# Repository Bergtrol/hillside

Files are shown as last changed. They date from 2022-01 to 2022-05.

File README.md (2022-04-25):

# Hillside Ergonomic Keyboards

Hillside is a small family of split ergonomic keyboards.

Hillside keyboard with nice!nano and switches Hillside 56, 52 and 48 keyboards

The boards are the:

- [Hillside 56](hillside56) with a physical arrow T cluster fully separate from the alpha keys. The most novice friendly, but the largest.
- [Hillside 52](hillside52) with ring and pinky splay and whose physical arrow keys steal one of the alpha keys. The best all around choice.
- [Hillside 48](hillside48) which is like a Ferris Sweep on steroids. The original and most compact.

Their key differences are:

| Board | Layout  | Arrow <br> T | Finger <br> Splay | Encoder <br> Spots / Side | Hotswap <br> Option| Thin <br> Layout | Thin <br> Size |
|:---|:---|:---:|:---:|:---:|:---:|:---:|:---:|
| [Hillside 56](hillside56) | 3x6+5+5 | yes |  no | 4 | yes | 3x5+4+5 | 48 |
| [Hillside 52](hillside52) | 3x6+3+5 | yes |  yes | 3 | yes | 3x5+2+5 | 44 |
| [Hillside 48](hillside48) | 3x6+1+5 | no |  no | 1 | no | 3x5+1+5 | 42 |

Their common features are:

- Choc-spaced keys, aggressive stagger, five thumb keys
- Break-off pinky column
- Tenting puck support
- QMK and ZMK firmware
- Nice!nano battery power switch
- Encoder support for one per side
- Haptic feedback header and mount
- Underglow from five SK6812-MINI-Es
- Reversible PCB which qualifies for AllPCB's free PCB
- Detailed BOM and default keyboard rational
- SMT diodes, resistors, capacitors, and reset switch

See the board readmes for details and default keymaps.

*Keycaps*: Hillside boards are _only_ suitable for choc v1 switches and keycaps based on an 18 x 17mm switch spacing, such as the [MBK](https://mkultra.click/mbk-choc-keycaps), [Lowprokb LDSA](https://lowprokb.ca/products/ldsa-low-profile-blank-keycaps) and [MoErgo MCC](https://mkultra.click/moergo-mcc-pom-1u-keycap/). Not MX ones, nor 18 x 18mm ones such as Work Louder, nor Kailh Choc Transparent.

## Hardware

See the [wiki](https://github.com/mmccoyd/hillside/wiki)
  for how to order PCBs and build the boards.

See [Forking and Modifying](https://github.com/mmccoyd/hillside/wiki/Forking%20and%20Modifying)
  on whether it would be difficult to modify these designs.

## Firmware

QMK includes firmware for [Hillside48](https://github.com/qmk/qmk_firmware/tree/master/keyboards/handwired/hillside).

ZMK firmware is at [Hillside ZMK Firmware](https://github.com/mmccoyd/zmk-config).

The default keymap is shared by both and is described in QMK.

## Acknowledgments

The awesome discord communities for Low Profile Keyboards and splitkb.com provided a fertile learning ground.
Several of the symbol and footprint files came from that community, as noted in the doc folder.
The keyboards I have used and read about also influenced these boards, including the
  [Atreus](https://shop.keyboard.io/products/keyboardio-atreus),
  [Lily58](https://github.com/kata0510/Lily58),
  [Kyria](https://splitkb.com/collections/keyboard-kits/products/kyria-pcb-kit),
  [Corne](https://github.com/foostan/crkbd) and
  [Ferris](https://github.com/pierrechevalier83/ferris).

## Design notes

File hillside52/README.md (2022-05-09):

# Hillside 52

Hillside 52 is a split ergonomic keyboard with 3x6+3+5 choc-spaced keys.
It has the aggressive stagger of the Ferris plus
  finger splay, a physical arrow T, a longer thumb arc
  and break-off outer pinky columns.

Hillside52 keyboard Hillside 52 keyboard

The arrow clusters provide a more familiar keymap for users new to small keyboards and provide utility keys for more seasoned users. See the Hillside [family readme](../README.md) for features common to all hillside boards. Specific to the Hillside 52 are: 

* One Encoder per side at either: upper or tucked thumb or lowest ring
* Reversible 100 x 143mm PCB, which qualifies for AllPCB's free PCB offer

## Keymap

The default keymap has physical arrow keys, alternate hand modifiers for all keys and a navigation and editing layer. See the [keymap descrition](https://github.com/mmccoyd/hillside/wiki/Hillside%2052%20Keymap) for details.

Hillside52 keyboard Hillside 52 keyboard three main layers (https://github.com/mmccoyd/hillside/wiki/Hillside%2052%20Keymap)

## Firmware

QMK: a fork I need to push, which will become a PR

<!---

[Hillside58 fork](https://github.com/mmccoyd/qmk_firmware)
to be pushed and added as PR to QMK.
-->

ZMK: TBD

# Why

A visually easy to use keyboard is useful. Either for people new to small keyboards or for a keyboard pulled from a dusty drawer a year from now. The physical arrow cluster of a 65% keyboard makes it more intuitive than a 60% keyboard, so adding an arrow T to a 40% board seemed a way to make using a 40% board more obvious.

I find a few extra keys laying around lets me have multiple approaches to things. This allows me to choose between approaches gradually over time.
Also, the extra keys fit within the existing Hillside48 footprint and the inner arrow might be a good thumb key.

## Images

<div style="background-color:#DCDCDC;">

Schematic
</div>

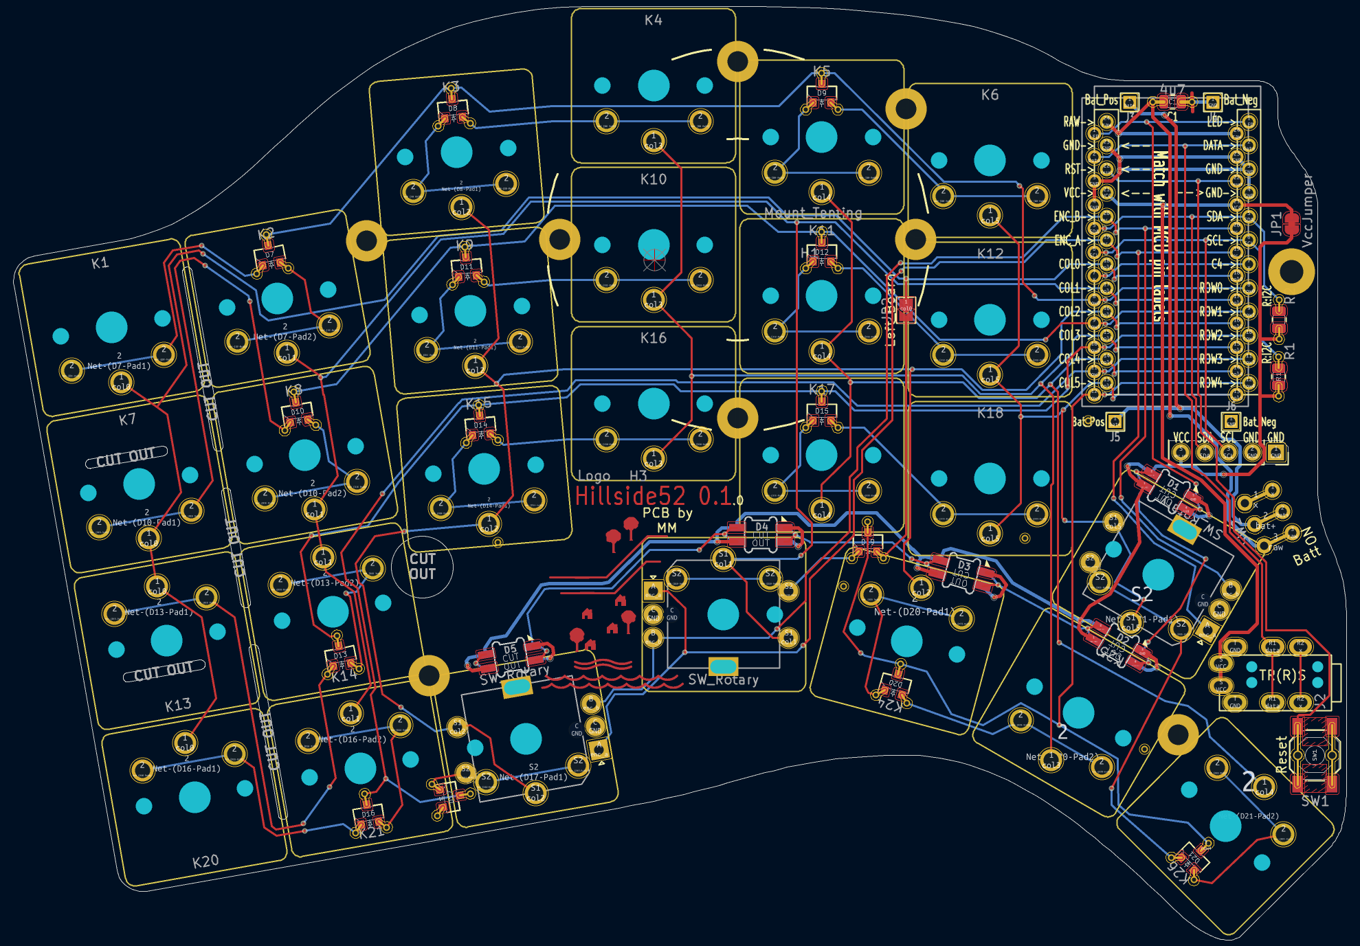
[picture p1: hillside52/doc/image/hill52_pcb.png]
pcb PCB


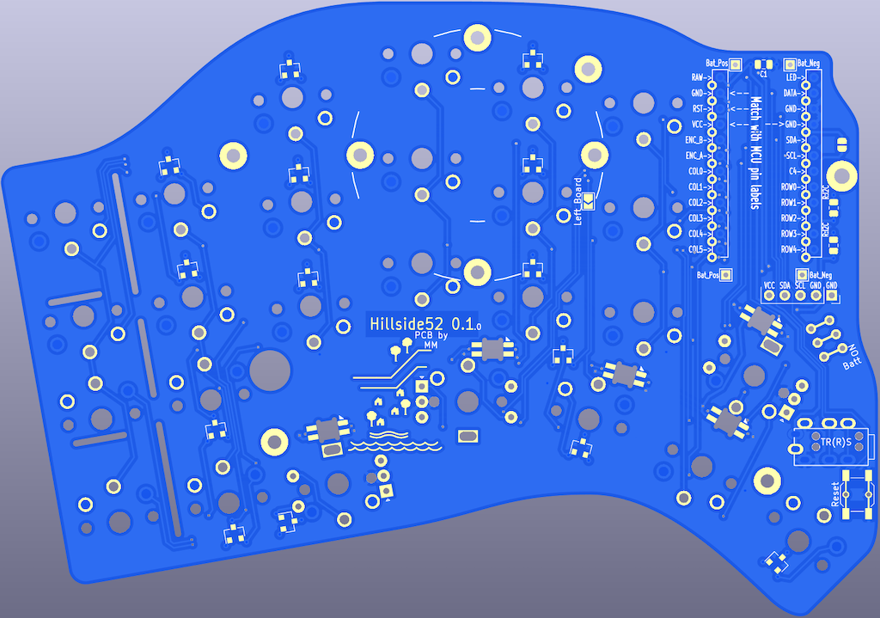
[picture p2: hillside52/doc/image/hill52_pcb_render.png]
render Front Render


<div style="background-color:#DCDCDC;">

To test if the key layout suits your fingers,
 print the below switch layout images in landscape mode.
(The images do not show well on a dark nighttime background.)

switches Switch Layout Left

switches Switch Layout Right
</div>

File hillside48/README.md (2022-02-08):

# Hillside48 Ergonomic Keyboard

Hillside48 is a split ergonomic keyboard with 3x6+4+2 choc-spaced keys. It has the aggressive stagger of the Ferris but a longer thumb arc and a break-off outer pinky column.

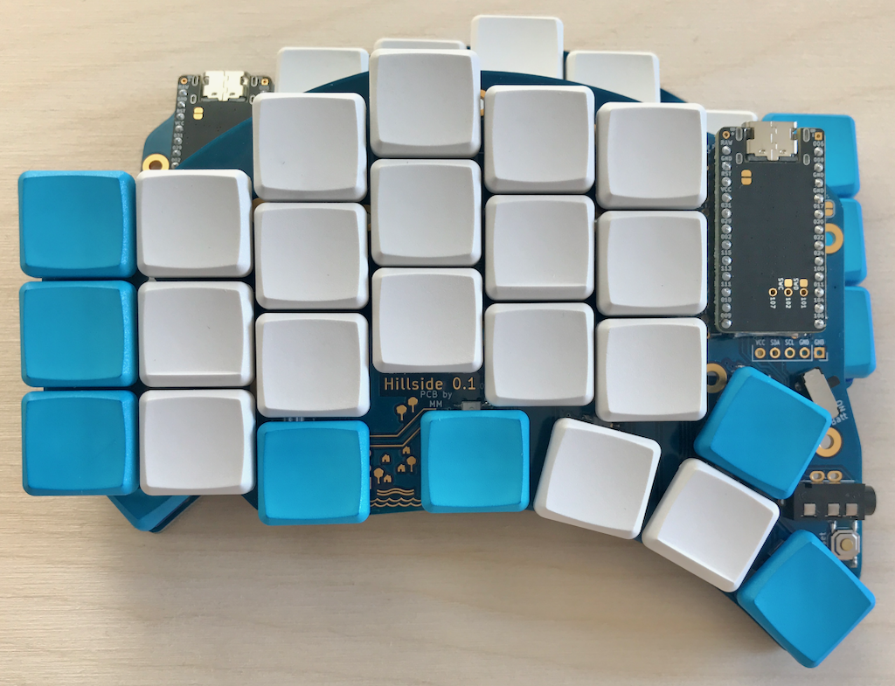
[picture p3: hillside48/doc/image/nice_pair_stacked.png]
Hillside keyboard with nice!nano and switches Keyboard with nice!nano and switches


So rather like a choc Kyria, minus two keys. With 42 to 48 keys it isn't minimalist,
  but it is compact on finger travel while still allowing roomy keymaps.

Features:
- 3x6+4+2 choc-spaced keys, aggressive stagger, four key thumb arc, break-off pinky column
- Tenting puck mount point
- QMK and ZMK firmware
- Nice!nano battery power switch and decoupling capacitor
- Encoder support under the ring fingers
- Haptic feedback header
- Underglow from five SK6812-MINI-Es
- Reversible 99 x 137mm PCB, which qualifies for AllPCB's free PCB offer
- Detailed BOM and default keyboard rational.
- SMT diodes, resistors, capacitors, and reset switch

Hillside48 is _only_ suitable for choc v1 switches and keycaps based on an 18 x 17mm switch spacing, such as the MBK keycaps. Not MX ones, nor 18 x 18mm ones such as Work Louder.

As the first Hillside board, it was originally just Hillside and is also just hillside/0_1 within the QMK firmware.

## Hardware

See the [wiki](https://github.com/mmccoyd/hillside/wiki)
  for how to order the PCB and build the board.
KiCad 6 was used to create the board gerbers.

See [Forking and Modifying](https://github.com/mmccoyd/hillside/wiki/Forking%20and%20Modifying)
  on whether it would be difficult to modify this design, for those that are interested.

## Firmware

QMK includes firmware for [Hillside](https://github.com/qmk/qmk_firmware/tree/master/keyboards/handwired/hillside).

For ZMK, firmware access is at [Hillside ZMK Firmware](https://github.com/mmccoyd/zmk-config).

The default keymap is shared by both and is described in QMK.

# Why

I wanted choc spacing but a key or so more than the Ferris and an outer pinky column. Instead of tweaking the 3x6 choc Corne I started a new PCB for more flexibility, though it grew to fill its footprint....

Moving around the switches of the Choc Corne did seem the easiest approach. But learning more than blind KiCad modification seemed a better idea, so I created a new PCB matching the Ferris column and thumb spacing.

I liked the bottom row keys of my Atreus, so I added two under the middle columns, where they seem unobtrusive. Then one shifted to the thumb arch, which seems more versatile. An upper thumb key seemed useful and combo-able without pushing the footprint. It has more keys than my initial idea, but that makes keymap evolution feel less tight.

It is like a Ferris Sweep on steroids, which wound up close to a Choc Kyria but requires board fabrication and SMT soldering.
Naming ideas included FeistyCorne, LongFir and LongSweep, but Hillside seemed the most fun.

## Acknowledgments

The awesome Low Profile Keyboards and splitkb.com discord communities provided a fertile learning ground for my keyboard explorations.
Several of the symbol and footprint files came from that community, as noted in the doc folder.
The keyboards I have used and read about also influenced this board including the
  [Atreus](https://shop.keyboard.io/products/keyboardio-atreus),
  [Lily58](https://github.com/kata0510/Lily58),
  [Kyria](https://splitkb.com/collections/keyboard-kits/products/kyria-pcb-kit),
  [Corne](https://github.com/foostan/crkbd) and
  [Ferris](https://github.com/pierrechevalier83/ferris).

## Images
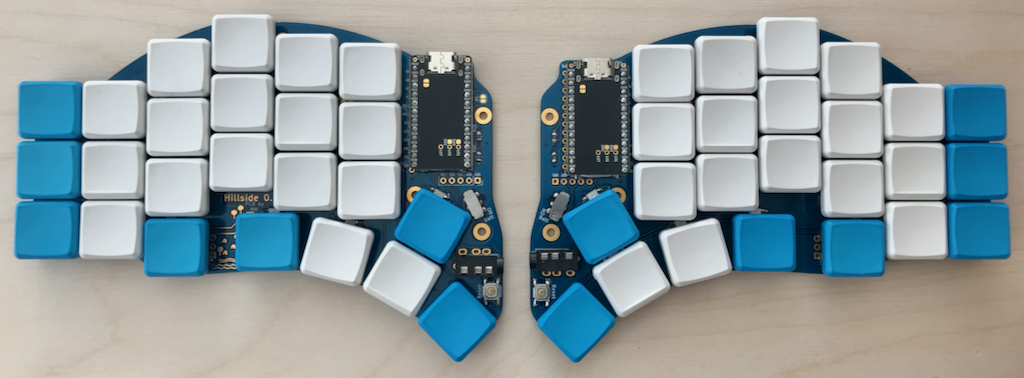
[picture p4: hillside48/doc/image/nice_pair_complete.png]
Both halves


<div style="background-color:#DCDCDC;">

Schematic
</div>

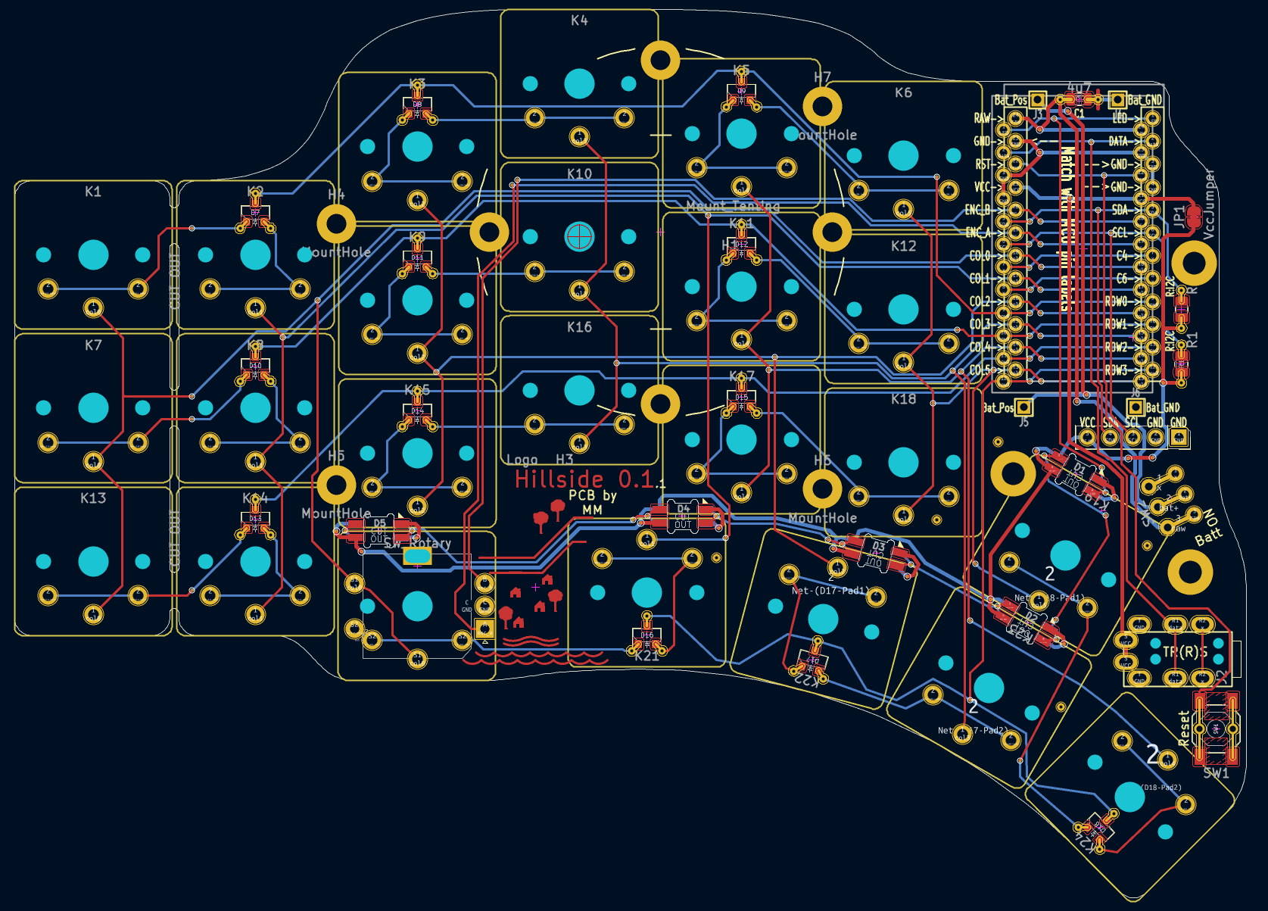
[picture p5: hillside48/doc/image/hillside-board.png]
pcb PCB


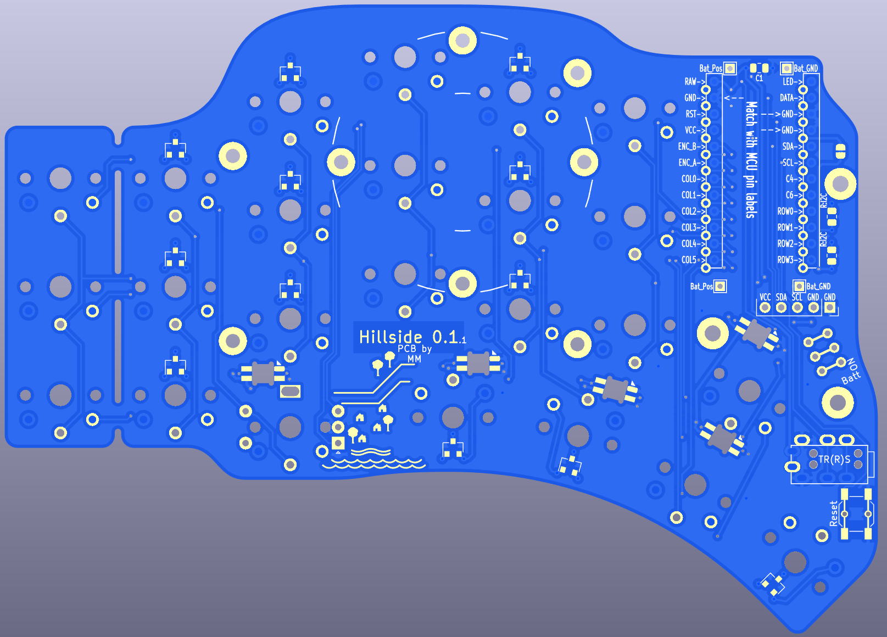
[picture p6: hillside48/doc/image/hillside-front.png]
render Front Render


<div style="background-color:#DCDCDC;">

To test if the key layout suits your fingers,
 print these in landscape mode.
switches Switch Layout Left

switches Switch Layout Right
</div>

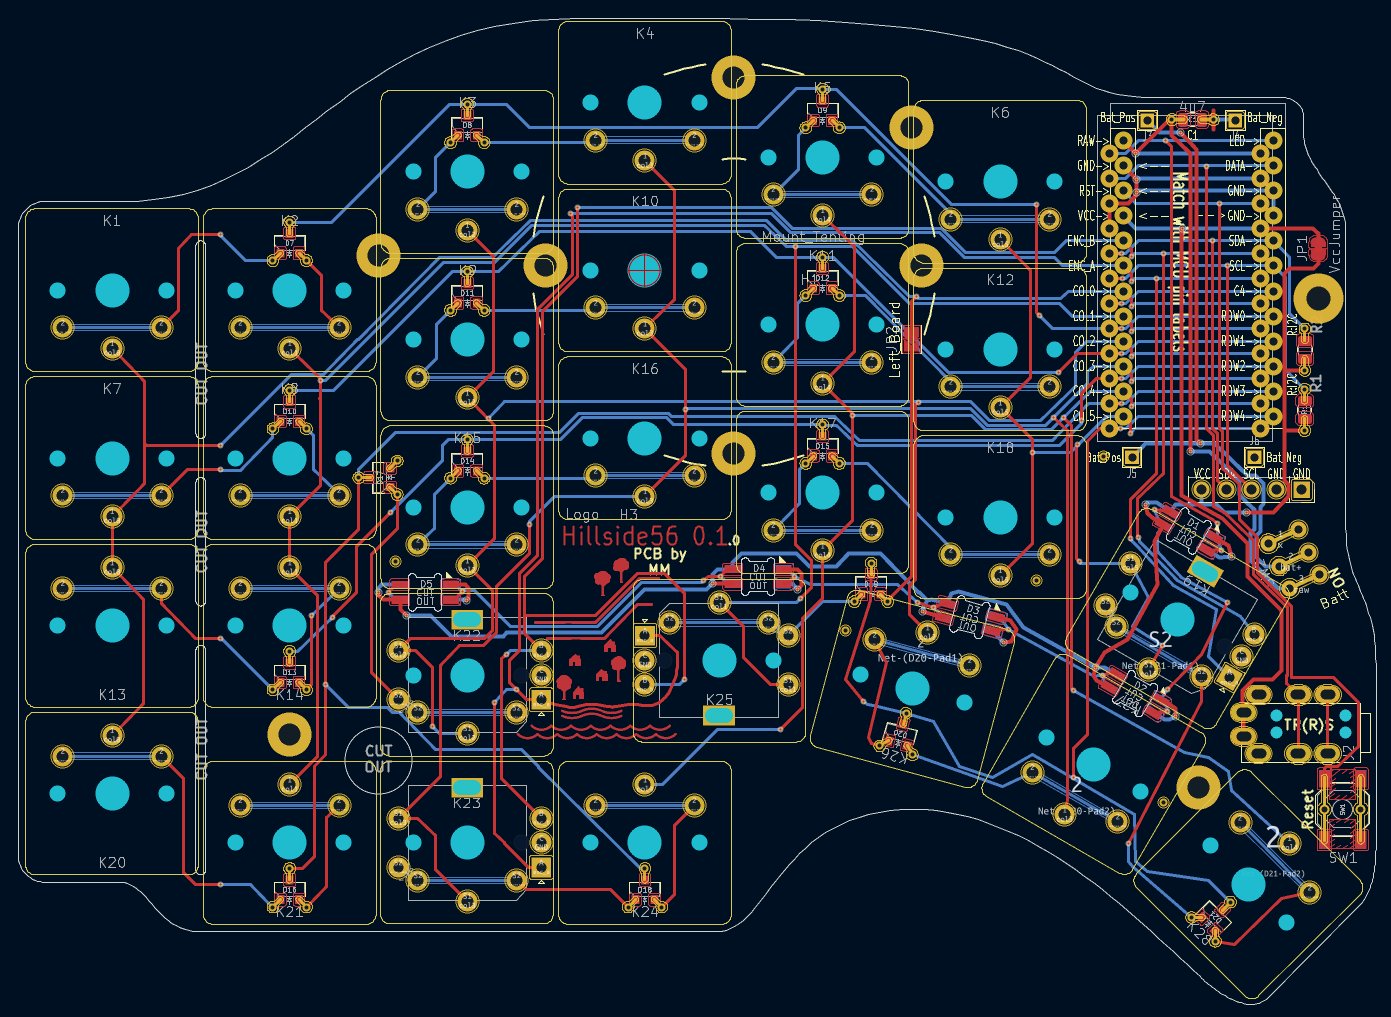
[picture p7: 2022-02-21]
hillside56/doc/image/hill56_pcb.png

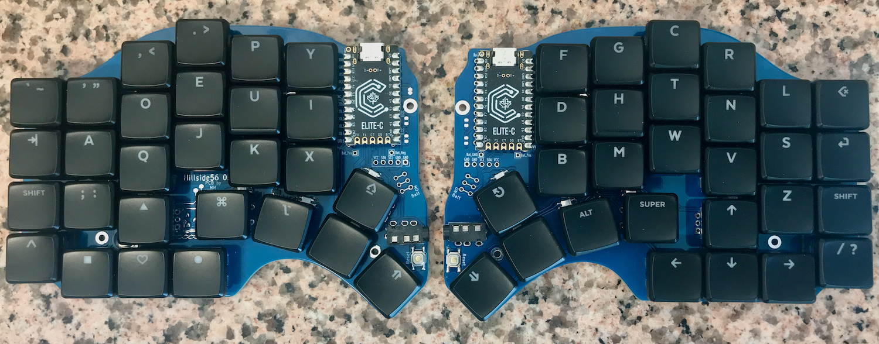
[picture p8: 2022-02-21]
hillside56/doc/image/hill56_photo_pair.png

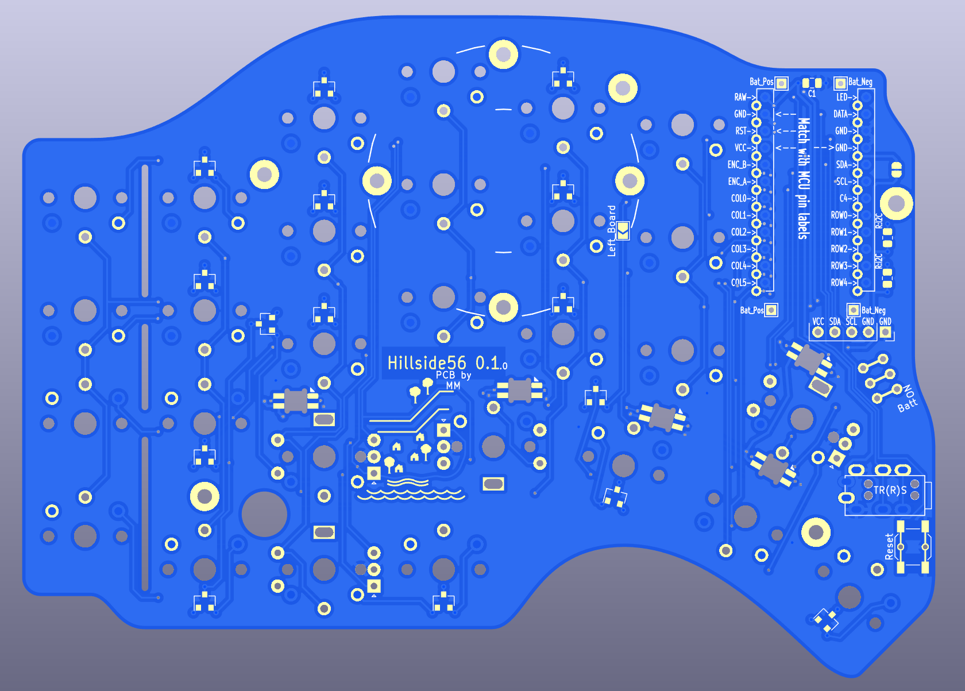
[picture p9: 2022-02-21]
hillside56/doc/image/hill56_pcb_render.png

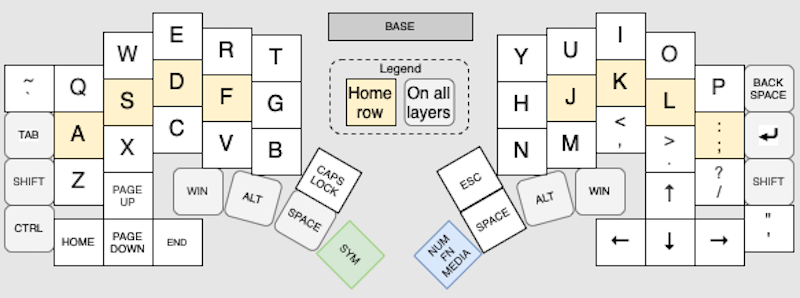
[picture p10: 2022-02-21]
hillside56/doc/image/hill56_keymap.png

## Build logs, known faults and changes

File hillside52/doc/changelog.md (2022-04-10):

# Version 0.1.0

The initial Hillside 52 release. The key differences from the Hillside 48 are:

- Total of 52 keys, adding an extra key under each pinky column.
- Space for physical arrow keys, using one alpha key for the up arrow.
- Splay of five and ten degrees for the ring and pinkey columns.
- Hotswap switch option using Mill-Max sockets.
- Three spots for one encoder per side.
- Cleaner method to remove outer pinky column.

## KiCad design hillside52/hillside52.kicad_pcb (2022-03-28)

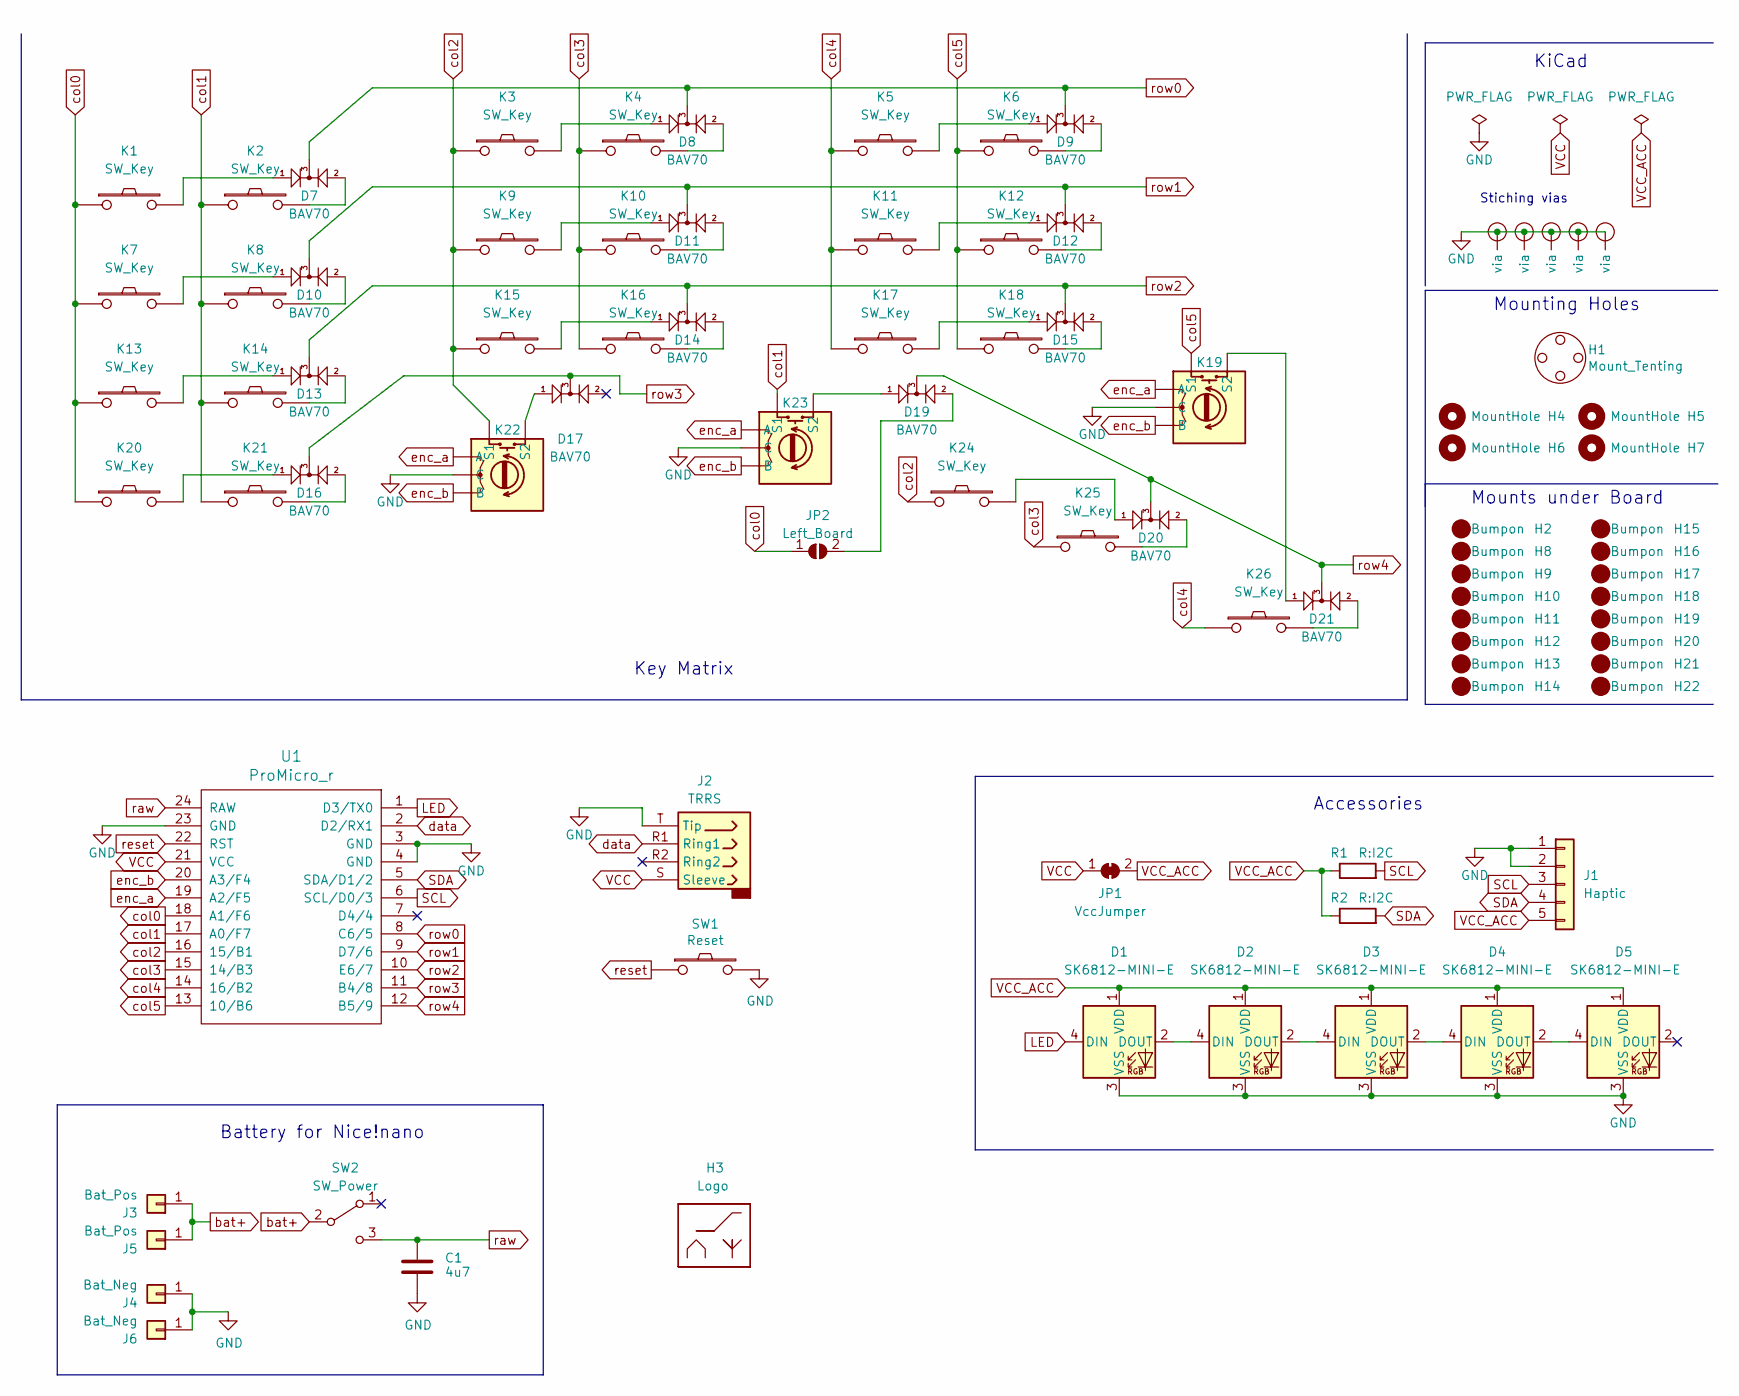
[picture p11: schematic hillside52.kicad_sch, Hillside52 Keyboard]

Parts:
C1: 4u7; C_0805_2012Metric
D1, D2, D3, D4, D5: SK6812-MINI-E
D7, D8, D9, D10, D11, D12, D13, D14, D15, D16, D17, D19, D20, D21: BAV70; SOT-23
H1: Mount_Tenting; Tenting_Puck
H2, H8, H9, H10, H11, H12, H13, H14, H15, H16, H17, H18, H19, H20, H21, H22: Bumpon
H3: Logo; Hillside_Logo
H4, H5, H6, H7: MountHole; MountingHole_2.2mm_with_PCB_insert_rings
J1: Haptic; Pimoroni_Haptic
J2: TRRS; MJ-4PP-9
J3, J5: Bat_Pos; 1pin_conn
J4, J6: Bat_Neg; 1pin_conn
JP1: VccJumper; SolderJumper-2_P1.3mm_Bridged_RoundedPad1.0x1.5mm
JP2: Left_Board; SolderJumper-2_P1.3mm_Open_TrianglePad1.0x1.5mm
K1, K2, K3, K4, K5, K6, K7, K8, K9, K10, K11, K12, K13, K14, K15, K16, K17, K18, K20, K21, K24, K25, K26: SW_Key; pg1350-R_hotswap
K19, K22, K23: SW_Rotary; pg1350-DR_rotary_hotswap
R1, R2: R:I2C; R_0805_2012Metric
SW1: Reset; SW_SPST_SKQG_WithStem
SW2: SW_Power; SW_SPDT_JS202011AQN
U1: ProMicro_r; ProMicro_v2
V1, V2, V3, V4, V5: Via; VIA-0.8mm

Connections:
GND: C1.2, D1.3 (VSS), D2.3 (VSS), D3.3 (VSS), D4.3 (VSS), D5.3 (VSS), J1.1, J1.2, J2.T (Tip), J4.1, J6.1, K19.C, K22.C, K23.C, SW1.2, U1.3 (GND), U1.4 (GND), U1.23 (GND), V1.1 (via), V2.1 (via), V3.1 (via), V4.1 (via), V5.1 (via)
LED: D1.4 (DIN), U1.1 (D3/TX0)
unnamed: D1.2 (DOUT), D2.4 (DIN)
unnamed: D2.2 (DOUT), D3.4 (DIN)
unnamed: D3.2 (DOUT), D4.4 (DIN)
unnamed: D4.2 (DOUT), D5.4 (DIN)
unnamed: D7.1 (A1), K1.2
unnamed: D7.2 (A2), K2.2
unnamed: D8.1 (A1), K3.2
unnamed: D8.2 (A2), K4.2
unnamed: D9.1 (A1), K5.2
unnamed: D9.2 (A2), K6.2
unnamed: D10.1 (A1), K7.2
unnamed: D10.2 (A2), K8.2
unnamed: D11.1 (A1), K9.2
unnamed: D11.2 (A2), K10.2
unnamed: D12.1 (A1), K11.2
unnamed: D12.2 (A2), K12.2
unnamed: D13.1 (A1), K13.2
unnamed: D13.2 (A2), K14.2
unnamed: D14.1 (A1), K15.2
unnamed: D14.2 (A2), K16.2
unnamed: D15.1 (A1), K17.2
unnamed: D15.2 (A2), K18.2
unnamed: D16.1 (A1), K20.2
unnamed: D16.2 (A2), K21.2
unnamed: D17.1 (A1), K22.S2
unnamed: D19.1 (A1), K23.S2
unnamed: D19.2 (A2), JP2.2 (B)
unnamed: D20.1 (A1), K24.2
unnamed: D20.2 (A2), K25.2
unnamed: D21.1 (A1), K19.S2
unnamed: D21.2 (A2), K26.2
SCL: J1.3, R1.2, U1.6 (SCL/D0/3)
SDA: J1.4, R2.2, U1.5 (SDA/D1/2)
VCC: J2.S (Sleeve), JP1.1 (A), U1.21 (VCC)
VCC_ACC: D1.1 (VDD), D2.1 (VDD), D3.1 (VDD), D4.1 (VDD), D5.1 (VDD), J1.5, JP1.2 (B), R1.1, R2.1
bat+: J3.1, J5.1, SW2.2 (B)
col0: JP2.1 (A), K1.1, K7.1, K13.1, K20.1, U1.18 (A1/F6)
col1: K2.1, K8.1, K14.1, K21.1, K23.S1, U1.17 (A0/F7)
col2: K3.1, K9.1, K15.1, K22.S1, K24.1, U1.16 (15/B1)
col3: K4.1, K10.1, K16.1, K25.1, U1.15 (14/B3)
col4: K5.1, K11.1, K17.1, K26.1, U1.14 (16/B2)
col5: K6.1, K12.1, K18.1, K19.S1, U1.13 (10/B6)
data: J2.R1 (Ring1), U1.2 (D2/RX1)
enc_a: K19.A, K22.A, K23.A, U1.19 (A2/F5)
enc_b: K19.B, K22.B, K23.B, U1.20 (A3/F4)
raw: C1.1, SW2.3 (C), U1.24 (RAW)
reset: SW1.1, U1.22 (RST)
row0: D7.3 (K), D8.3 (K), D9.3 (K), U1.8 (C6/5)
row1: D10.3 (K), D11.3 (K), D12.3 (K), U1.9 (D7/6)
row2: D13.3 (K), D14.3 (K), D15.3 (K), U1.10 (E6/7)
row3: D16.3 (K), D17.3 (K), U1.11 (B4/8)
row4: D19.3 (K), D20.3 (K), D21.3 (K), U1.12 (B5/9)

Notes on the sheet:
KiCad
Mounting Holes
Key Matrix
Battery for Nice!nano
Stiching vias
Mounts under Board
Accessories

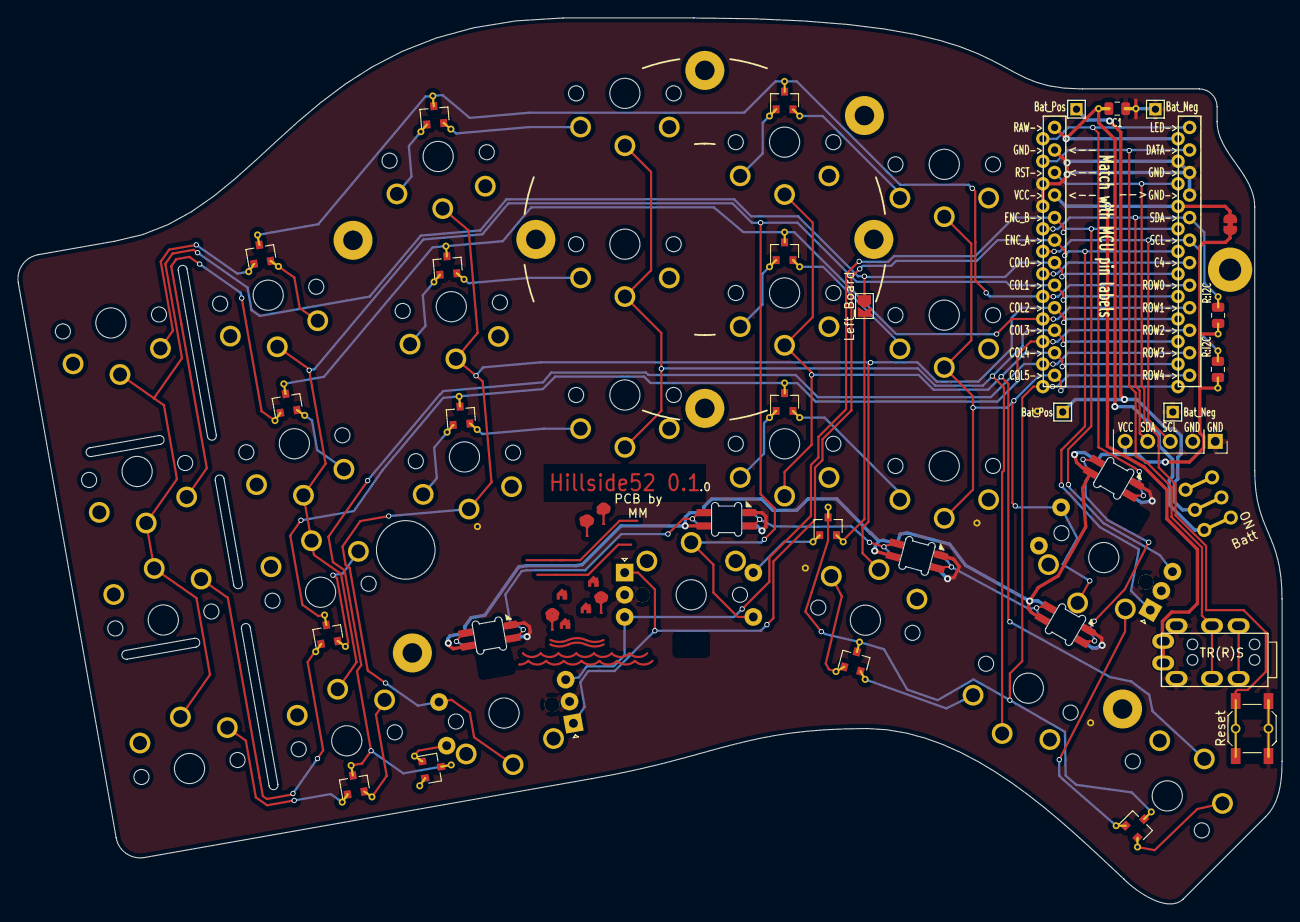
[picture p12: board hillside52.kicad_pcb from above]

Board: 2 copper layers, 142.5 x 99.9 mm, 86 parts (0 on the bottom side), 54 nets.

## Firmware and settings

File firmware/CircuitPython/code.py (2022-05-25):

print("Starting setup...")

import board
from kmk.kmk_keyboard import KMKKeyboard
from kmk.keys import KC
from kmk.modules.layers import Layers

from kmk.scanners.keypad import MatrixScanner

print("Initializing keyboard...")

keyboard = KMKKeyboard()

keyboard.modules.append(Layers())

# keyboard.debug_enabled = True

keyboard.matrix = [
                    MatrixScanner(column_pins=(board.GP5,board.GP4,board.GP3,board.GP2,board.GP1,board.GP0),
                                  row_pins=(board.GP6,board.GP7,board.GP8,board.GP9)),
                    MatrixScanner(column_pins=(board.GP10,board.GP11,board.GP12,board.GP13,board.GP14,board.GP15),
                                  row_pins=(board.GP16,board.GP17,board.GP18,board.GP19))
                  ]

keyboard.coord_mapping = [ 
    0,  1,  2,  3,  4,  5,                  24, 25, 26, 27, 28, 29,
    6,  7,  8,  9,  10, 11,                 30, 31, 32, 33, 34, 35,
    12, 13, 14, 15, 16, 17,                 36, 37, 38, 39, 40, 41,
                           21,           44,
            20,    22, 23, 19, 18,   47, 46, 42, 43,    45,
    ]

# KMK Layer Mods
# --------------
# KC.DF(layer)	    Switches the default layer until the next time the keyboard powers off
# KC.MO(layer)	    Momentarily activates layer, switches off when you let go
# KC.LM(layer, mod)	As MO(layer) but with mod active
# KC.LT(layer, kc)	Momentarily activates layer if held, sends kc if tapped
# KC.TG(layer)	    Toggles the layer (enables it if no active, and vise versa)
# KC.TO(layer)	    Activates layer and deactivates all other layers
# KC.TT(layer)	    Momentarily activates layer if held, toggles it if tapped repeatedly

Num = KC.MO(1)
Nav = KC.MO(2)
Sym = KC.MO(3) 

WordL = KC.LALT(KC.LEFT)
WordR = KC.LALT(KC.RIGHT)

Undo = KC.LGUI(KC.Z)
Cut = KC.LGUI(KC.X)
Copy = KC.LGUI(KC.C)
Paste = KC.LGUI(KC.V)
Redo = KC.LGUI(KC.Y)

vsNavB = KC.LCTL(KC.MINS)
vsNavF = KC.LCTL(KC.LSFT(KC.MINS))
    
keyboard.keymap = [
    # Base layer
    #-------+-------+-------+-------+-------+-------+                                      +-------+-------+-------+-------+-------+-------+
    #  TAB  |   Q   |   W   |   F   |   P   |   G   |                                      |   J   |   L   |   U   |   Y   |   ;   |   '   |
    #-------+-------+-------+-------+-------+-------|                                      |-------+-------+-------+-------+-------+-------|
    #  CRTL |   A   |   R   |   S   |   T   |   D   |                                      |   H   |   N   |   E   |   I   |   O   | ENTER |
    #-------+-------+-------+-------+-------+-------+-------+                      +-------+-------+-------+-------+-------+-------+-------|
    # SHIFT |   Z   |   X   |   C   |   V   |   B   |       |                      |   -   |   K   |   M   |   ,   |   .   |   /   | SHIFT |
    #-------+-------+-------+-------+-------+-------+-------+-------+      +-------+-------+-------+-------+-------+-------+-------+-------+
    #               |       |       |  GUI  |  ALT  | SPACE |  Nav  |      |  Sym  | BKSPC |  Num  |  Nav  |       |       |
    #               +-------+       +-------+-------+-------+-------+      +-------+-------+-------+-------+       +-------+
    [
        KC.TAB,  KC.Q, KC.W, KC.F, KC.P,  KC.G,                                      KC.J, KC.L, KC.U,    KC.Y,   KC.SCLN, KC.QUOT,
        KC.LCTL, KC.A, KC.R, KC.S, KC.T,  KC.D,                                      KC.H, KC.N, KC.E,    KC.I,   KC.O,    KC.ENTER,
        KC.LSFT, KC.Z, KC.X, KC.C, KC.V,  KC.B,                                      KC.K, KC.M, KC.COMM, KC.DOT, KC.SLSH, KC.RSFT, 
                                                  KC.NO,                  KC.MINS,
                       KC.NO,    KC.LGUI,KC.LALT, KC.SPC,  Nav,         Sym, KC.BKSP, Num, Nav,             KC.NO,
    ],

    # Number layer
    #-------+-------+-------+-------+-------+-------+                                      +-------+-------+-------+-------+-------+-------+
    #       |       |       |       |       |       |                                      |       |   7   |   8   |   9   |   =   |       |
    #-------+-------+-------+-------+-------+-------|                                      |-------+-------+-------+-------+-------+-------|
    #       |       |       |       |       |       |                                      |       |   4   |   5   |   6   |   -   |   /   |
    #-------+-------+-------+-------+-------+-------+-------+                      +-------+-------+-------+-------+-------+-------+-------|
    #       |       |       |       |       |       |       |                      |       |   0   |   1   |   2   |   3   |   +   |   *   |
    #-------+-------+-------+-------+-------+-------+-------+-------+      +-------+-------+-------+-------+-------+-------+-------+-------+
    #               |       |       |       |       | SPACE |       |      |       | BKSPC |       |   ,   |       |   .   |
    #               +-------+       +-------+-------+-------+-------+      +-------+-------+-------+-------+       +-------+
    [
        KC.NO, KC.NO, KC.NO, KC.NO, KC.NO, KC.NO,                                      KC.NO, KC.N7, KC.N8, KC.N9, KC.EQL, KC.NO,
        KC.NO, KC.NO, KC.NO, KC.NO, KC.NO, KC.NO,                                      KC.NO, KC.N4, KC.N5, KC.N6, KC.PMNS, KC.LPRN,
        KC.NO, KC.NO, KC.NO, KC.NO, KC.NO, KC.NO,                                      KC.N0, KC.N1, KC.N2, KC.N3, KC.PPLS, KC.ASTR, 
                                                  KC.NO,                      KC.NO,
                      KC.NO,        KC.NO, KC.NO, KC.SPC, KC.NO,        KC.NO, KC.BKSP, KC.NO, KC.COMM,     KC.PDOT,
    ],

    # Navigation layer
    #-------+-------+-------+-------+-------+-------+                                      +-------+-------+-------+-------+-------+-------+
    #  ESC  |       |       |       |       | VOL+  |                                      |       | HOME  |   ↑   |  END  | PGUP  |       |
    #-------+-------+-------+-------+-------+-------|                                      |-------+-------+-------+-------+-------+-------|
    #       |       |  ALT  | CTRL  | SHIFT | VOL-  |                                      |       |   ←   |   ↓   |   →   |PGDOWN |       |
    #-------+-------+-------+-------+-------+-------+-------+                      +-------+-------+-------+-------+-------+-------+-------|
    # SHIFT | Undo  |  Cut  | Copy  | Paste | Redo  | MPLAY |                      |       |       | WordL |       | WordR |vsNavB |vsNavF |
    #-------+-------+-------+-------+-------+-------+-------+-------+      +-------+-------+-------+-------+-------+-------+-------+-------+
    #               |       |       |       |       |       |       |      |       | BKSPC |       |       |       |       |
    #               +-------+       +-------+-------+-------+-------+      +-------+-------+-------+-------+       +-------+
    [
        KC.ESC,  KC.NO, KC.NO,    KC.NO,   KC.NO,  KC.VOLU,                                    KC.NO, KC.HOME,  KC.UP,   KC.END,   KC.PGUP,  KC.NO,
        KC.NO,   KC.NO, KC.LALT, KC.LCTL, KC.LSFT, KC.VOLD,                                    KC.NO, KC.LEFT, KC.DOWN, KC.RIGHT, KC.PGDOWN, KC.NO,
        KC.LSFT, Undo,   Cut,     Copy,    Paste,   Redo,                                      KC.NO,  WordL,   KC.NO,   WordR,    vsNavB,   vsNavF, 
                                                           KC.MPLY,                    KC.NO,
                        KC.NO,             KC.NO,   KC.NO,  KC.NO, KC.NO,      KC.NO, KC.BKSP, KC.NO, KC.NO,             KC.NO,
    ],

    # Symbol layer
    #-------+-------+-------+-------+-------+-------+                                      +-------+-------+-------+-------+-------+-------+
    #   `   |   !   |   @   |   #   |   $   |   %   |                                      |   ^   |   &   |   *   |   (   |   )   |   _   |
    #-------+-------+-------+-------+-------+-------|                                      |-------+-------+-------+-------+-------+-------|
    #   F1  |  F2   |  F3   |  F4   |  F5   |  F6   |                                      |   |   |   [   |   ]   |   {   |   }   |       |
    #-------+-------+-------+-------+-------+-------+-------+                      +-------+-------+-------+-------+-------+-------+-------|
    #   F7  |  F8   |  F9   |  F10  |  F11  |  F12  |       |                      |       |   /   |       |       |       |       |       |
    #-------+-------+-------+-------+-------+-------+-------+-------+      +-------+-------+-------+-------+-------+-------+-------+-------+
    #               | CTRL  |       | SHIFT |  ALT  | SPACE |       |      |       | BKSPC |       |       |       |       |
    #               +-------+       +-------+-------+-------+-------+      +-------+-------+-------+-------+       +-------+
    [
        KC.GRAVE,KC.EXLM, KC.AT, KC.HASH, KC.DLR, KC.PERC,                                     KC.CIRC, KC.AMPR, KC.ASTR, KC.LPRN, KC.RPRN, KC.UNDS,
        KC.F1,   KC.F2,   KC.F3,  KC.F4,  KC.F5,   KC.F6,                                      KC.PIPE,  KC.LBRC,   KC.RBRC,   KC.LCBR,   KC.RCBR,  KC.NO,
        KC.F7,   KC.F8,   KC.F9,  KC.F10, KC.F11,  KC.F12,                                     KC.PSLS, KC.NO, KC.NO, KC.NO, KC.NO, KC.NO, 
                                                         KC.NO,                        KC.NO,
                         KC.LCTL,        KC.LSFT,  KC.LALT, KC.SPC, KC.NO,         KC.NO, KC.BKSP, KC.NO, KC.NO,     KC.NO,
    ],
]

print("Setup complete, time to get CLACK-A-LACK-ING!")

if __name__ == '__main__':
    keyboard.go()

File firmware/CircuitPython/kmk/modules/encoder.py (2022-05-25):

# See docs/encoder.md for how to use

import busio
import digitalio
from supervisor import ticks_ms

from kmk.modules import Module

# NB : not using rotaryio as it requires the pins to be consecutive


class BaseEncoder:

    VELOCITY_MODE = True

    def __init__(self, is_inverted=False):

        self.is_inverted = is_inverted

        self._state = None
        self._direction = None
        self._pos = 0
        self._button_state = True
        self._button_held = None
        self._velocity = 0

        self._movement = 0
        self._timestamp = ticks_ms()

        # callback functions on events. Need to be defined externally
        self.on_move_do = None
        self.on_button_do = None

    def get_state(self):
        return {
            'direction': self.is_inverted and -self._direction or self._direction,
            'position': self.is_inverted and -self._pos or self._pos,
            'is_pressed': not self._button_state,
            'velocity': self._velocity,
        }

        # Called in a loop to refresh encoder state

    def update_state(self):
        # Rotation events
        new_state = (self.pin_a.get_value(), self.pin_b.get_value())

        if new_state != self._state:
            # it moves !
            self._movement += 1
            # false / false and true / true are common half steps
            # looking on the step just before helps determining
            # the direction
            if new_state[0] == new_state[1] and self._state[0] != self._state[1]:
                if new_state[1] == self._state[0]:
                    self._direction = 1
                else:
                    self._direction = -1

            # when the encoder settles on a position (every 2 steps)
            if new_state == (True, True):
                if self._movement > 2:
                    # 1 full step is 4 movements, however, when rotated quickly,
                    # some steps may be missed. This makes it behaves more
                    # naturally
                    real_movement = round(self._movement / 4)
                    self._pos += self._direction * real_movement
                    if self.on_move_do is not None:
                        for i in range(real_movement):
                            self.on_move_do(self.get_state())
                # Reinit to properly identify new movement
                self._movement = 0
                self._direction = 0

            self._state = new_state

        # Velocity
        self.velocity_event()

        # Button event
        self.button_event()

    def velocity_event(self):
        if self.VELOCITY_MODE:
            new_timestamp = ticks_ms()
            self._velocity = new_timestamp - self._timestamp
            self._timestamp = new_timestamp

    def button_event(self):
        raise NotImplementedError('subclasses must override button_event()!')

    # return knob velocity as milliseconds between position changes (detents)
    # for backwards compatibility
    def vel_report(self):
        # print(self._velocity)
        return self._velocity


class GPIOEncoder(BaseEncoder):
    def __init__(self, pin_a, pin_b, pin_button=None, is_inverted=False):
        super().__init__(is_inverted)

        self.pin_a = EncoderPin(pin_a)
        self.pin_b = EncoderPin(pin_b)
        self.pin_button = (
            EncoderPin(pin_button, button_type=True) if pin_button is not None else None
        )

        self._state = (self.pin_a.get_value(), self.pin_b.get_value())

    def button_event(self):
        if self.pin_button:
            new_button_state = self.pin_button.get_value()
            if new_button_state != self._button_state:
                self._button_state = new_button_state
                if self.on_button_do is not None:
                    self.on_button_do(self.get_state())


class EncoderPin:
    def __init__(self, pin, button_type=False):
        self.pin = pin
        self.button_type = button_type
        self.prepare_pin()

    def prepare_pin(self):
        if self.pin is not None:
            self.io = digitalio.DigitalInOut(self.pin)
            self.io.direction = digitalio.Direction.INPUT
            self.io.pull = digitalio.Pull.UP
        else:
            self.io = None

    def get_value(self):
        return self.io.value


class I2CEncoder(BaseEncoder):
    def __init__(self, i2c, address, is_inverted=False):

        try:
            from adafruit_seesaw import digitalio, neopixel, rotaryio, seesaw
        except ImportError:
            print('seesaw missing')
            return

        super().__init__(is_inverted)

        self.seesaw = seesaw.Seesaw(i2c, address)

        # Check for correct product

        seesaw_product = (self.seesaw.get_version() >> 16) & 0xFFFF
        if seesaw_product != 4991:
            print('Wrong firmware loaded?  Expected 4991')

        self.encoder = rotaryio.IncrementalEncoder(self.seesaw)
        self.seesaw.pin_mode(24, self.seesaw.INPUT_PULLUP)
        self.switch = digitalio.DigitalIO(self.seesaw, 24)
        self.pixel = neopixel.NeoPixel(self.seesaw, 6, 1)

        self._state = self.encoder.position

    def update_state(self):

        # Rotation events
        new_state = self.encoder.position
        if new_state != self._state:
            # it moves !
            self._movement += 1
            # false / false and true / true are common half steps
            # looking on the step just before helps determining
            # the direction
            if self.encoder.position > self._state:
                self._direction = 1
            else:
                self._direction = -1
            self._state = new_state
            self.on_move_do(self.get_state())

        # Velocity
        self.velocity_event()

        # Button events
        self.button_event()

    def button_event(self):
        if not self.switch.value and not self._button_held:
            # Pressed
            self._button_held = True
            if self.on_button_do is not None:
                self.on_button_do(self.get_state())

        if self.switch.value and self._button_held:
            # Released
            self._button_held = False

    def get_state(self):
        return {
            'direction': self.is_inverted and -self._direction or self._direction,
            'position': self._state,
            'is_pressed': not self.switch.value,
            'is_held': self._button_held,
            'velocity': self._velocity,
        }
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

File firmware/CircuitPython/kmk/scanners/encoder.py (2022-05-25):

import keypad
import rotaryio

from kmk.scanners import Scanner


class RotaryioEncoder(Scanner):
    def __init__(self, pin_a, pin_b, divisor=4):
        self.encoder = rotaryio.IncrementalEncoder(pin_a, pin_b, divisor)
        self.position = 0
        self._pressed = False
        self._queue = []

    @property
    def key_count(self):
        return 2

    def scan_for_changes(self):
        position = self.encoder.position

        if position != self.position:
            self._queue.append(position - self.position)
            self.position = position

        if not self._queue:
            return

        key_number = self.offset
        if self._queue[0] > 0:
            key_number += 1

        if self._pressed:
            self._queue[0] -= 1 if self._queue[0] > 0 else -1

            if self._queue[0] == 0:
                self._queue.pop(0)

            self._pressed = False

        else:
            self._pressed = True

        return keypad.Event(key_number, self._pressed)

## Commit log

2022-01-14 Hill52 Initial: copy from Hillside
    [hillside.kicad_pcb, hillside.kicad_sch]
2022-01-14 Hill52 Initial: rename files and internal links
    [hillside52.kicad_pcb, hillside52.kicad_sch]
2022-01-14 Move alpha-key row nets up one pin on MCU
    [hillside52.kicad_pcb, hillside52.kicad_sch]
2022-01-14 Add two lower pinkie keys, update outer edge cut
    [hillside52.kicad_pcb, hillside52.kicad_sch]
2022-01-15 schema: Encoder wired into extra row, not thumb's
    [hillside52.kicad_sch]
2022-01-18 Handedness Jumper. Rotate lower pinkies for bumpon
    - Bat_Neg pads not Bat_GND
    [hillside52.kicad_pcb, hillside52.kicad_sch]
2022-01-24 Footprint: Bumpon
2022-01-24 Footprint: Mounting hole with PCB insert rings
2022-01-24 Footprint: Promicro one more row pin label
2022-01-24 Footprint: Holes of promicro for bottom plate
2022-01-24 Footprint: Holes of key switch for bottom plate
2022-01-24 Hillside56 Arrow clusters. Four encoder spots/side
    - Two additional keys per side to form arrow cluster
    - Mark where bumpons fit on board bottom around edge and components
    - Mounting holes set for use with PCB threaded inserts in bottom plate
    - Handedness jumper in key matrix
    - Extend edgecut 0.75 mm for more space for a bottom plate with cutouts
    - Rotate several keys for more bumpon room around edge
    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
    [hillside52.kicad_pcb, hillside52.kicad_sch]
2022-01-24 Project file: Layer view presets Gerber and Clean
2022-01-24 Rename to Hillside56, update files
    [hillside56.kicad_pcb, hillside56.kicad_sch]
2022-01-24 Rename model directory
    [hillside56.kicad_pcb, hillside56.kicad_sch]
2022-01-24 - ignore file KiCad 6 notes
2022-01-24 ref: PCB threaded insert specs
2022-01-24 - minor arc diffs from reopening
    [hillside56.kicad_pcb]
2022-01-24 - ignore gerber, .svg, .dxf files in output dir
2022-01-24 Hillside56 v0.1.0-alpha
    - 'Cut Out' for interior edge cut
    - Update sheet dates to today
    [hillside56.kicad_pcb, hillside56.kicad_sch]
2022-01-24 Gerbers Hillside56 v0.1.0-alpha
    [hillside56-B_Cu.gbr, hillside56-B_Mask.gbr, hillside56-B_Silkscreen.gbr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]
2022-01-24 Remove gerbers
    [hillside56-B_Cu.gbr, hillside56-B_Mask.gbr, hillside56-B_Silkscreen.gbr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]
2022-01-24 - tweak switch symbol locations in arrow cluster
    [hillside56.kicad_sch]
2022-01-24 - Readme within gerber folder
2022-01-24 - update sheet descriptions
    [hillside56.kicad_pcb, hillside56.kicad_sch]
2022-02-07 Move hillside original board into hillside48/
    [hillside.kicad_pcb, hillside.kicad_sch, hillside.sch]
2022-02-07 Reorg: docs into 48, 48 and lib to top level
    [hillside.kicad_pcb, hillside.kicad_sch, hillside.sch]
2022-02-07 Split readme into family and board
2022-02-08 - re-org fixup: re-add kicad and kicad/lib
2022-02-08 - re-org fixup: move hillside56 to top level
    [hillside56.kicad_pcb, hillside56.kicad_sch]
2022-02-20 Remove alpha designation
    [hillside56.kicad_pcb, hillside56.kicad_sch]
2022-03-26 52 Hill52 Initial: copy from 56
    [hillside52.kicad_pcb, hillside52.kicad_sch]
2022-03-26 52 Initial: change 56 to 52
    [hillside52.kicad_pcb, hillside52.kicad_sch]
2022-03-26 52: Remove extra keys, Splay 5 and 10, pinky align
    [hillside52.kicad_pcb, hillside52.kicad_sch]
2022-03-27 Footprint: Switch with hotswap sized pads
2022-03-27 Footprint: Switch rotary, trim courtyard area
2022-03-27 Footprint: Logo trim wave extent
2022-03-27 Footprint: Switch rotary: hotswap pads
2022-03-27 52: Doc: Gerber readme update, drill sizes, ignore
2022-03-28 56: KiCad 6.0.4 open, fill, DRC and save
    [hillside56.kicad_pcb]
2022-03-28 56: Breakaway tracks on edges, extra break slots
    [hillside56.kicad_pcb]
2022-03-28 56 PCB: Use hotswap switches, bump version number
    [hillside56.kicad_pcb]
2022-03-28 56: Scheme use hotswap switches
    [hillside56.kicad_sch]
2022-03-28 56: Reference 50 mm ruler
    [hillside56.kicad_pcb]
2022-03-28 - 56: Reference ruler force to show millimeters
    [hillside56.kicad_pcb]
2022-03-28 52: Hotswap footprints, cleanup tracks
    - Move base mount, and diode, closer to edge
    - PCB: tweak scale ruler, cleanup traces across splays, broken tracks
    - Scheme: Trim switch numbers, Hotswap footprints
    - Use switches with larger pads for hotswap
    - KiCad 6.0.4 and save/load churn
    [hillside52.kicad_pcb, hillside52.kicad_sch]
2022-05-09 52: Images of PCB, schematic, switches, render
2022-05-25 Added CircuitPython KMK firmware implementation for hand-wired version running RPPico
